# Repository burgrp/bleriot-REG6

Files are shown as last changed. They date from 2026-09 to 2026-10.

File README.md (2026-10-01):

# BleRiot REG6

REG6 is a six-channel solid-state-relay controller built around a
PY32F030 and PAN2110. This repository contains the KiCad hardware and a
standalone TinyGo/BleRiot module under `fw/` that exposes one integer percentage
for each channel.

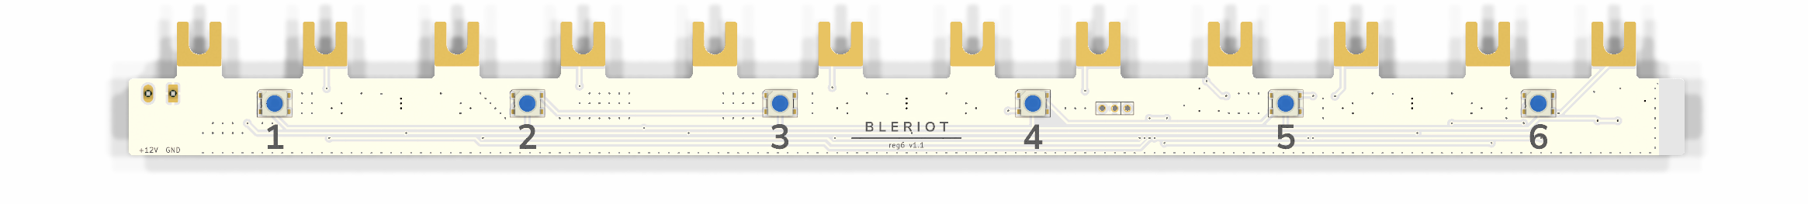
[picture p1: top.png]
REG6 - top

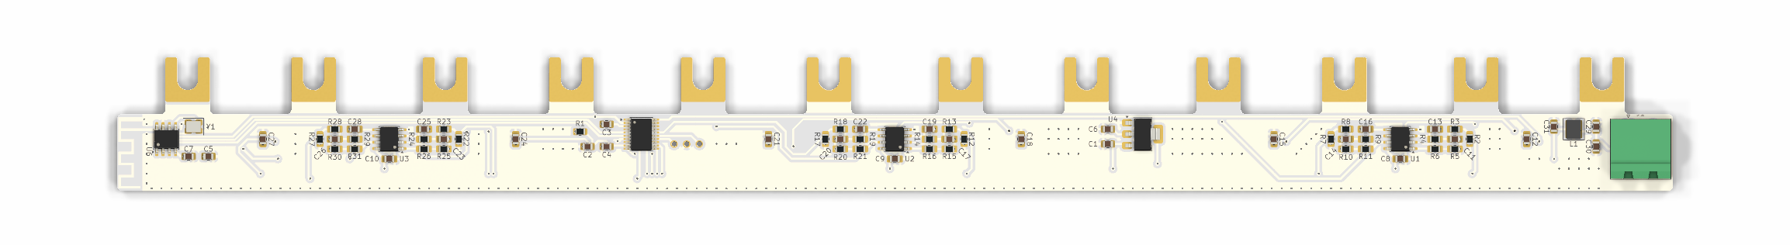
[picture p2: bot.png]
REG6 - bottom


## Hardware

The firmware targets a PY32F030x8 at 24 MHz. TIM1 and TIM3 generate all six
PWM outputs in hardware at a common 24 kHz frequency. Each analog path uses a
loaded two-stage 1.5 kOhm/100 nF RC ladder, whose poles are approximately
405 Hz and 2.78 kHz, followed by an LM358 with a nominal gain of 1.56. At 50%
duty, the ideal nominal filter model predicts about 12 mV peak-to-peak ripple
at 24 kHz, compared with about 2.56 V peak-to-peak at 1 kHz. The PAN2110 uses the
BleRiot three-wire SPI driver, and six chained WS2812B LEDs report channel and
link state.

| Function | MCU pin | Peripheral | Alternate function |
|---|---|---|---:|
| PWM channel 1 | PA8 | TIM1_CH1 | AF2 |
| PWM channel 2 | PA9 | TIM1_CH2 | AF2 |
| PWM channel 3 | PA10 | TIM1_CH3 | AF2 |
| PWM channel 4 | PB4 | TIM3_CH1 | AF1 |
| PWM channel 5 | PB5 | TIM3_CH2 | AF1 |
| PWM channel 6 | PF3 | TIM3_CH3 | AF13 |
| PAN2110 CSN | PF1 | GPIO | - |
| PAN2110 SCK | PA2 | GPIO, bit-banged SPI | - |
| PAN2110 DATA | PA3 | GPIO, bidirectional SPI | - |
| WS2812B data, D1-D6 | PF4 | GPIO | - |

The development inventory uses raw RF channel 37 with BLE Coded PHY S8. Its
address and XTEA key were generated offline with BleRiot's `node new` command
and are baked into the image by `node build`. This checked-in identity is public
bench provisioning; deployments must use a separately generated private
inventory identity and key.

## Registers

The `ssr` inventory instance publishes exactly these writable Registry
registers:

| Registry name | Wire tag | Registry type | Range |
|---|---:|---|---:|
| `ssr.channel.1` | 1 | int | 0..100 |
| `ssr.channel.2` | 2 | int | 0..100 |
| `ssr.channel.3` | 3 | int | 0..100 |
| `ssr.channel.4` | 4 | int | 0..100 |
| `ssr.channel.5` | 5 | int | 0..100 |
| `ssr.channel.6` | 6 | int | 0..100 |
| `ssr.watchdog` | 7 | int | 0..60 seconds |

Values are direct integer percentages on the Registry and `int32` wire protocol.
Firmware clamps assignments to 0..100, and a Registry NULL assignment clears
that channel to zero. `ssr.watchdog` is a lease counter. Positive writes arm it
for up to 60 seconds, with larger values clamped to 60; zero, negative, and NULL
writes expire it. Reads return the remaining whole seconds rounded up, or zero
at and after the monotonic deadline.
Register tags are permanent wire identities and must not be renumbered or
reused.

## Status And Safety

While BleRiot is online and the watchdog is armed, each LED represents its
matching channel level. Status indicators use the WS2812 driver's global
brightness of 128/255 (approximately 50%); normal channel colors render at half
that, approximately 25%.

The watchdog starts expired. While it is expired, channel SET requests are
acknowledged but ignored. Expiry clears all six retained channel levels and
forces both PWM timers to 0% duty. Writing a positive watchdog value re-arms
channel writes but does not restore cleared levels; every active channel needs
a fresh SET. While the radio remains online and the watchdog is expired, only
D2 blinks pure blue using the BleRiot heartbeat phase.

The node starts offline. If no valid packet has arrived, or packets stop for
more than five seconds, firmware clears all six retained levels and forces both
timers to update with 0% duty immediately. D1 then pulses orange-red for 200 ms
once per second; D2-D6 remain off. A radio initialization failure follows the
same safe output and heartbeat behavior. Reconnection does not restore old
levels: each active channel requires a fresh SET. This RF-offline indication
has priority over the online watchdog-expired indication.

## Build And Run

The module uses released BleRiot and TinyGo driver modules pinned in `fw/go.mod`.
Install TinyGo and the PY32 pyOCD pack, then run:

```sh
go -C fw test ./...
make -C fw build
make -C fw install-pack
make -C fw flash
```

Firmware v0.1.0 was built with Go 1.26.3, TinyGo commit
`f8e1f465ecae33c58772c099f9b7667c00cea9c1`, LLVM 18.1.8, pyOCD 0.44.0, and
the Puya PY32F030 CMSIS pack 1.2.8.

`make -C fw flash` builds the `ssr` inventory instance, programs it through
pyOCD, and opens RTT under reset. Confirm the intended board and probe before
using that target. To inspect generated firmware without flashing:

```sh
go -C fw run ./cmd/dev node build --name ssr
go -C fw run ./cmd/dev node gen --name ssr
```

Run the hub against a Registry service with:

```sh
go -C fw run ./cmd/dev hub --registry http://localhost:8080 --diagnostics rf
```

With the hub and Registry running, `./fw/color-test.sh` continuously renews a
five-second watchdog lease before writing the six demonstration channel levels.
Set the `REGISTRY` environment variable to use a URL other than
`http://localhost:8080`.

`make -C fw new` prints another random inventory stub; it does not update the
checked-in development identity automatically.

## Bench Validation

Perform initial validation with low-voltage loads only and no mains connected:

1. Build and flash the firmware, then verify D1 pulses orange-red and every PWM pin
   is low before the hub sends a valid packet.
2. Start the hub, arm `ssr.watchdog`, and write 0, 50, and 100 to each Registry
   channel in turn.
   Scope PA8, PA9, PA10, PB4, PB5, and PF3; expect a constant low at 0%, a
   24 kHz waveform at 50%, and a constant high at 100% duty.
3. Confirm D1-D6 track their corresponding values using the configured level
   colors, with the chain limited to approximately 25% brightness.
4. Set a short watchdog lease and all channels nonzero, then stop renewing the
   watchdog while RF stays online. Verify every PWM output goes low, all channel
   GETs return zero, and only D2 blinks pure blue. Confirm channel SETs remain
   ineffective until the watchdog is re-armed, and that re-arming alone does
   not restore outputs.
5. Set all channels nonzero, stop RF traffic for more than five seconds, and
   verify every PWM output goes low and only D1 pulses orange-red for 200 ms per
   second, even after the watchdog expires.
6. Restore RF traffic without sending SETs and confirm all outputs remain off.
   Re-arm the watchdog, send fresh channel SETs, and verify only those channels
   resume.
7. Repeat power-up with the PAN2110 unavailable or misconfigured and confirm
   all PWM outputs remain low while the offline heartbeat continues.

After logic-level validation, verify the complete channel output stages and
load polarity against the schematic before connecting actual SSR loads.

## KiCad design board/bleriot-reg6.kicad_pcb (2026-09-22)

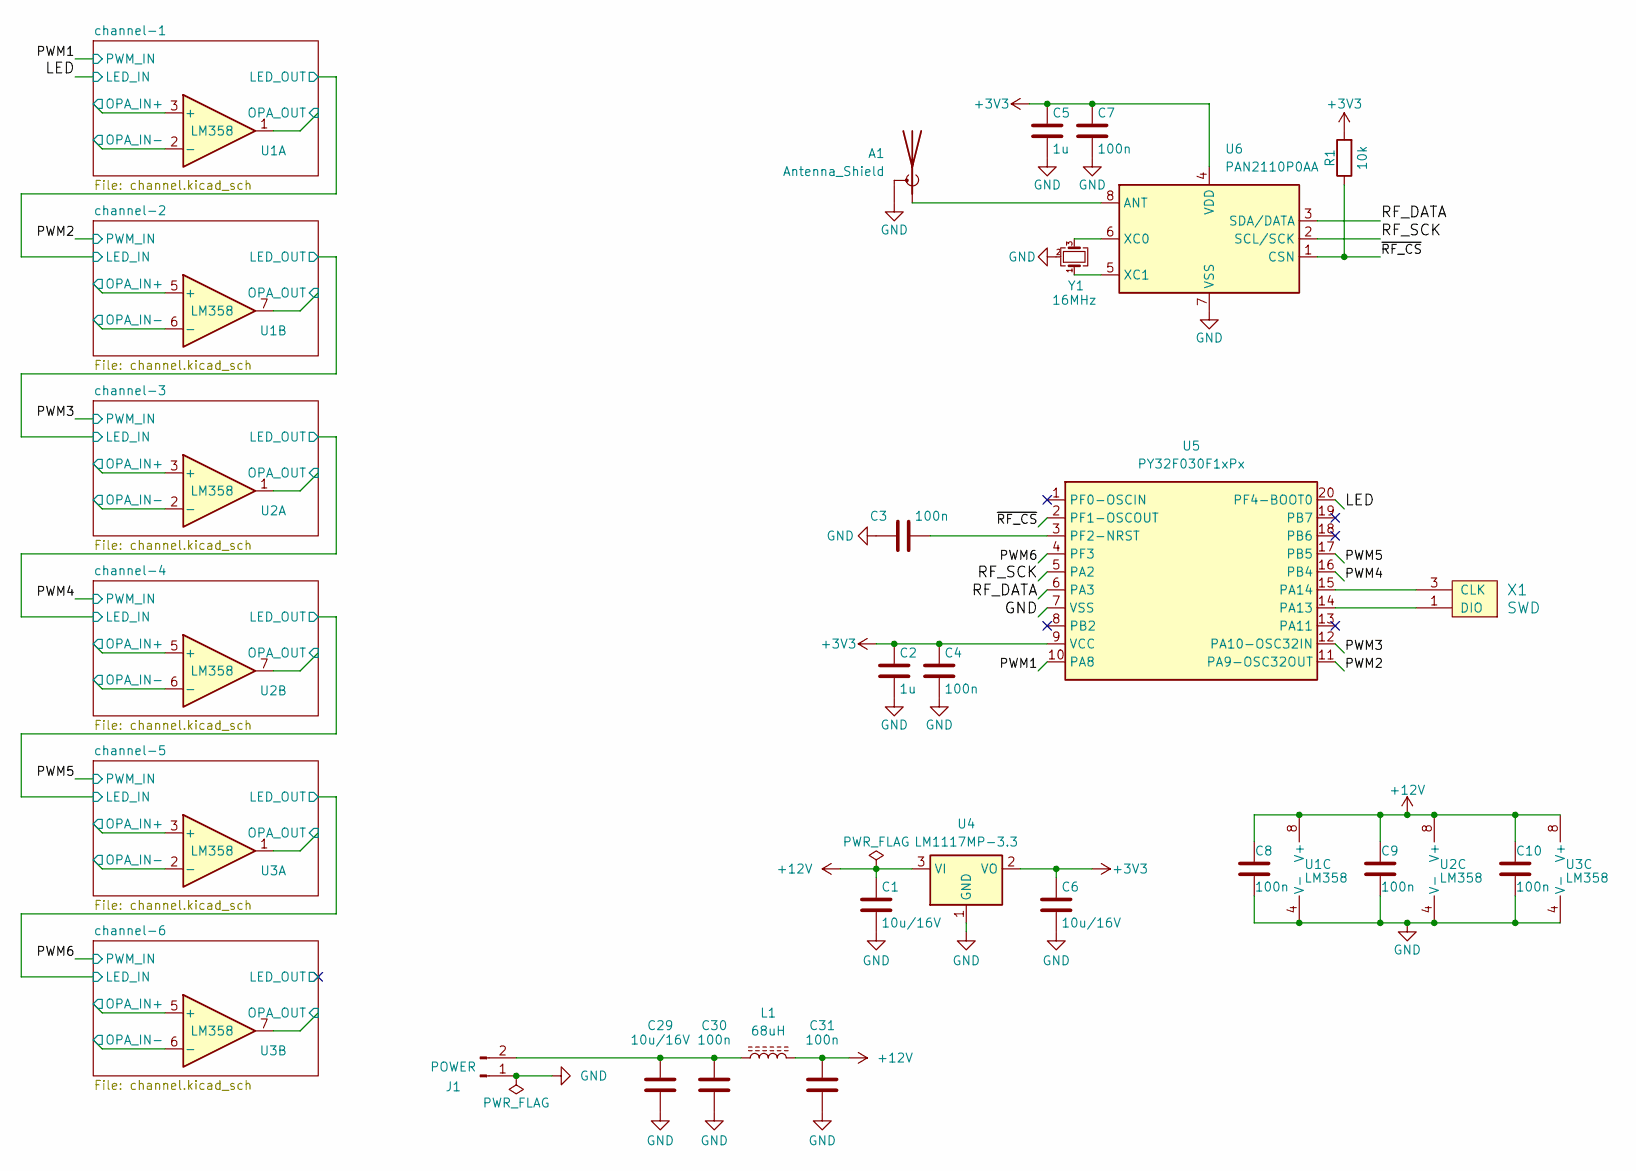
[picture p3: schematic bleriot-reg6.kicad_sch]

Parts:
A1: Antenna_Shield; Texas_SWRA117D_2.4GHz_Left
C1, C6, C29: 10u/16V; C_0805_2012Metric
C2, C5: 1u; C_0805_2012Metric
C3, C4, C7, C30, C31: 100n; C_0805_2012Metric
C8, C9, C10: 100n; C_0805_2012Metric_Pad1.18x1.45mm_HandSolder
J1: POWER; PhoenixContact_MSTBA_2,5_2-G_1x02_P5.00mm_Horizontal
L1: 68uH; L_Wuerth_MAPI-4020
R1: 10k; R_0805_2012Metric
U1, U2, U3: LM358; SOIC-8_3.9x4.9mm_P1.27mm
U4: LM1117MP-3.3; SOT-223-3_TabPin2
U5: PY32F030F1xPx; TSSOP-20_4.4x6.5mm_P0.65mm
U6: PAN2110P0AA; SOIC-8_3.9x4.9mm_P1.27mm
X1: SWD
Y1: 16MHz; Crystal_SMD_3225-4Pin_3.2x2.5mm

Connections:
+3V3: C2.1, C4.1, C5.1, C6.1, C7.1, R1.2, U4.2 (VO), U5.9 (VCC), U6.4 (VDD); also elsewhere on the board
+12V: C1.1, C8.1, C9.1, C10.1, C31.1, L1.2, U1.8 (V+), U2.8 (V+), U3.8 (V+), U4.3 (VI)
/LED: U5.20 (PF4-BOOT0); also elsewhere on the board
/PWM1: U5.10 (PA8); also elsewhere on the board
/PWM2: U5.11 (PA9-OSC32OUT); also elsewhere on the board
/PWM3: U5.12 (PA10-OSC32IN); also elsewhere on the board
/PWM4: U5.16 (PB4); also elsewhere on the board
/PWM5: U5.17 (PB5); also elsewhere on the board
/PWM6: U5.4 (PF3); also elsewhere on the board
/RF_DATA: U5.6 (PA3), U6.3 (SDA/DATA)
/RF_SCK: U5.5 (PA2), U6.2 (SCL/SCK)
/channel-1/OPA_IN+: U1.3 (+); also elsewhere on the board
/channel-1/OPA_IN-: U1.2 (-); also elsewhere on the board
/channel-1/OPA_OUT: U1.1; also elsewhere on the board
/channel-2/OPA_IN+: U1.5 (+); also elsewhere on the board
/channel-2/OPA_IN-: U1.6 (-); also elsewhere on the board
/channel-2/OPA_OUT: U1.7; also elsewhere on the board
/channel-3/OPA_IN+: U2.3 (+); also elsewhere on the board
/channel-3/OPA_IN-: U2.2 (-); also elsewhere on the board
/channel-3/OPA_OUT: U2.1; also elsewhere on the board
/channel-4/OPA_IN+: U2.5 (+); also elsewhere on the board
/channel-4/OPA_IN-: U2.6 (-); also elsewhere on the board
/channel-4/OPA_OUT: U2.7; also elsewhere on the board
/channel-5/OPA_IN+: U3.3 (+); also elsewhere on the board
/channel-5/OPA_IN-: U3.2 (-); also elsewhere on the board
/channel-5/OPA_OUT: U3.1; also elsewhere on the board
/channel-6/OPA_IN+: U3.5 (+); also elsewhere on the board
/channel-6/OPA_IN-: U3.6 (-); also elsewhere on the board
/channel-6/OPA_OUT: U3.7; also elsewhere on the board
/~RF_CS: R1.1, U5.2 (PF1-OSCOUT), U6.1 (CSN)
GND: A1.2 (Shield), C1.2, C2.2, C3.2, C4.2, C5.2, C6.2, C7.2, C8.2, C9.2, C10.2, C29.2, C30.2, C31.2, J1.1, U1.4 (V-), U2.4 (V-), U3.4 (V-), U4.1 (GND), U5.7 (VSS), U6.7 (VSS), X1.2 (GND), Y1.2 (G), Y1.4 (G); also elsewhere on the board
unnamed: A1.1 (A), U6.8 (ANT)
unnamed: C29.1, C30.1, J1.2, L1.1
unnamed: U5.14 (PA13), X1.1 (DIO)
unnamed: U5.15 (PA14), X1.3 (CLK)
unnamed: C3.1, U5.3 (PF2-NRST)
unnamed: U6.6 (XC0), Y1.3
unnamed: U6.5 (XC1), Y1.1

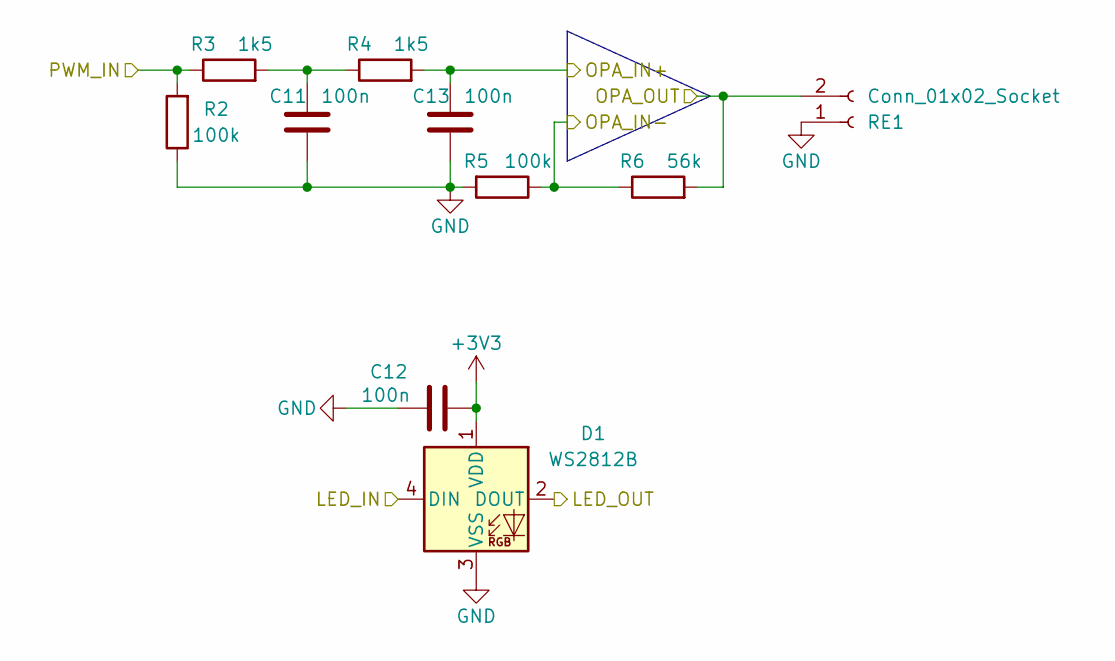
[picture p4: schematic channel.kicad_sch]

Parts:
C11, C12, C13: 100n; C_0805_2012Metric_Pad1.18x1.45mm_HandSolder
D1: WS2812B; LED_WS2812B_PLCC4_5.0x5.0mm_P3.2mm
R2, R5: 100k; R_0805_2012Metric_Pad1.20x1.40mm_HandSolder
R3, R4: 1k5; R_0805_2012Metric_Pad1.20x1.40mm_HandSolder
R6: 56k; R_0805_2012Metric_Pad1.20x1.40mm_HandSolder
RE1: Conn_01x02_Socket; ssr-contact

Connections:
+3V3: C12.2, D1.1 (VDD); also elsewhere on the board
/LED: D1.4 (DIN); also elsewhere on the board
/PWM1: R2.2, R3.1; also elsewhere on the board
/channel-1/LED_OUT: D1.2 (DOUT); also elsewhere on the board
/channel-1/OPA_IN+: C13.1, R4.2; also elsewhere on the board
/channel-1/OPA_IN-: R5.1, R6.1; also elsewhere on the board
/channel-1/OPA_OUT: R6.2, RE1.2; also elsewhere on the board
GND: C11.2, C12.1, C13.2, D1.3 (VSS), R2.1, R5.2, RE1.1; also elsewhere on the board
unnamed: C11.1, R3.2, R4.1

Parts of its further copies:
C14, C15, C16, C17, C18, C19, C20, C21, C22, C23, C24, C25, C26, C27, C28: 100n; C_0805_2012Metric_Pad1.18x1.45mm_HandSolder
D2, D3, D4, D5, D6: WS2812B; LED_WS2812B_PLCC4_5.0x5.0mm_P3.2mm
R7, R10, R12, R15, R17, R20, R22, R25, R27, R30: 100k; R_0805_2012Metric_Pad1.20x1.40mm_HandSolder
R8, R9, R13, R14, R18, R19, R23, R24, R28, R29: 1k5; R_0805_2012Metric_Pad1.20x1.40mm_HandSolder
R11, R16, R21, R26, R31: 56k; R_0805_2012Metric_Pad1.20x1.40mm_HandSolder
RE2, RE3, RE4, RE5, RE6: Conn_01x02_Socket; ssr-contact

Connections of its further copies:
+3V3: C15.2, C18.2, C21.2, C24.2, C27.2, D2.1 (VDD), D3.1 (VDD), D4.1 (VDD), D5.1 (VDD), D6.1 (VDD); also elsewhere on the board
/PWM2: R7.2, R8.1; also elsewhere on the board
/PWM3: R12.2, R13.1; also elsewhere on the board
/PWM4: R17.2, R18.1; also elsewhere on the board
/PWM5: R22.2, R23.1; also elsewhere on the board
/PWM6: R27.2, R28.1; also elsewhere on the board
/channel-1/LED_OUT: D2.4 (DIN); also elsewhere on the board
/channel-2/LED_OUT: D2.2 (DOUT), D3.4 (DIN)
/channel-2/OPA_IN+: C16.1, R9.2; also elsewhere on the board
/channel-2/OPA_IN-: R10.1, R11.1; also elsewhere on the board
/channel-2/OPA_OUT: R11.2, RE2.2; also elsewhere on the board
/channel-3/LED_OUT: D3.2 (DOUT), D4.4 (DIN)
/channel-3/OPA_IN+: C19.1, R14.2; also elsewhere on the board
/channel-3/OPA_IN-: R15.1, R16.1; also elsewhere on the board
/channel-3/OPA_OUT: R16.2, RE3.2; also elsewhere on the board
/channel-4/LED_OUT: D4.2 (DOUT), D5.4 (DIN)
/channel-4/OPA_IN+: C22.1, R19.2; also elsewhere on the board
/channel-4/OPA_IN-: R20.1, R21.1; also elsewhere on the board
/channel-4/OPA_OUT: R21.2, RE4.2; also elsewhere on the board
/channel-5/LED_OUT: D5.2 (DOUT), D6.4 (DIN)
/channel-5/OPA_IN+: C25.1, R24.2; also elsewhere on the board
/channel-5/OPA_IN-: R25.1, R26.1; also elsewhere on the board
/channel-5/OPA_OUT: R26.2, RE5.2; also elsewhere on the board
/channel-6/LED_OUT: D6.2 (DOUT)
/channel-6/OPA_IN+: C28.1, R29.2; also elsewhere on the board
/channel-6/OPA_IN-: R30.1, R31.1; also elsewhere on the board
/channel-6/OPA_OUT: R31.2, RE6.2; also elsewhere on the board
GND: C14.2, C15.1, C16.2, C17.2, C18.1, C19.2, C20.2, C21.1, C22.2, C23.2, C24.1, C25.2, C26.2, C27.1, C28.2, D2.3 (VSS), D3.3 (VSS), D4.3 (VSS), D5.3 (VSS), D6.3 (VSS), R7.1, R10.2, R12.1, R15.2, R17.1, R20.2, R22.1, R25.2, R27.1, R30.2, RE2.1, RE3.1, RE4.1, RE5.1, RE6.1; also elsewhere on the board
unnamed: C14.1, R8.2, R9.1
unnamed: C17.1, R13.2, R14.1
unnamed: C20.1, R18.2, R19.1
unnamed: C23.1, R23.2, R24.1
unnamed: C26.1, R28.2, R29.1

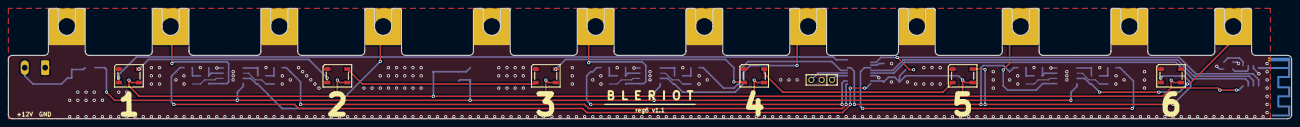
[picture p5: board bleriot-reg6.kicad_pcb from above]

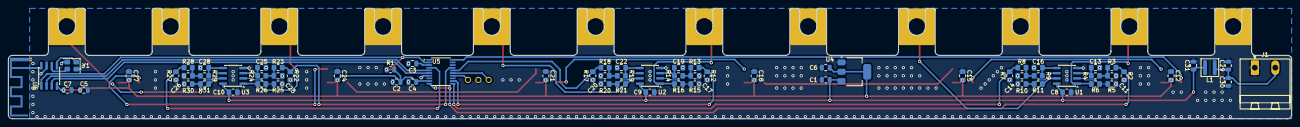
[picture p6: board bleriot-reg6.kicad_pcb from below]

Board: 2 copper layers, 314.0 x 27.0 mm, 85 parts (72 on the bottom side), 49 nets.

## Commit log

2026-09-02 Add initial REG6 hardware design
    Copilot-Session: 109a56b3-5fb8-400b-b74c-480b8f593743
    [bleriot-reg6.kicad_pcb, bleriot-reg6.kicad_sch, channel.kicad_sch]
2026-09-22 Update Bleriot board files with footprint and clearance adjustments
    - Modified copper edge clearance values in `bleriot-reg6.kicad_pro` to correct DRC exclusions.
    - Changed footprint for a connector in `bleriot-reg6.kicad_sch` from Phoenix MC to MSTB series.
    - Updated UUIDs and adjusted dimensions for pads and lines in `ssr-contact.kicad_mod` to enhance layout accuracy.
    [bleriot-reg6.kicad_pcb, bleriot-reg6.kicad_sch]
2026-10-01 Add watchdog safety register and tune LED brightness
    Add writable ssr.watchdog register (tag 7, 0..60 s) as a monotonic lease:
    expiry clears all channels and forces PWM off, channel SETs are ignored
    while expired, and re-arming requires fresh channel SETs. Blink D2 pure
    blue when online and expired; RF-offline indication keeps priority.
    Render normal channel colors at half intensity while keeping status
    indicators at full brightness.
